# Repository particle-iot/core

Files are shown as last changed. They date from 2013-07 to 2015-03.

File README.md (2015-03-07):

The Spark Core
=====

These are the hardware design files for the Spark Core, developed by Hex Labs, Inc. dba Spark.

These files have been made available online through a [Creative Commons Attribution-ShareAlike 3.0](http://creativecommons.org/licenses/by-sa/3.0/) license.

You are welcome to distribute, remix, and use these files for commercial purposes. If you do so, please attribute the original design to Spark both on the website and on the physical packaging of the product or in the instruction manual. All derivative works must be published under the same or a similar license.

## The Story

Development of the Spark Core in its current form began in January 2013 in Shenzhen, China during Spark's participation in the HAXLR8R hardware accelerator.  Development of the Spark Cloud was started in December 2011 as software infrastructure to support the Spark Socket.  Between January and May of 2013, the Spark Core and Cloud were developed from prototypes to a functional platform for building internet-connected hardware.  On May 2, 2013, the Spark Core was launched on the crowdfunding platform Kickstarter.  On May 17, 2013, the hardware design files for the product were released here on GitHub for others to use and learn from.

## What's Included

**BOM** — Current bill of materials for the latestversion of the Spark Core.  Includes part number labels from design files, component values, quantities, and package types.

**Datasheets** — Datasheets for the various components included on the Spark Core, including the STM32F103CBT6 microcontroller and the CC3000 Wi-Fi module.

**EAGLE** — Schematic and board files for the Spark Core.  We use EAGLE, a freemium PCB design software package, for the design and development of the Spark Core.

**Gerber** — Complete set of Gerber files for the current version of the Core.  Use these files to spin up and assemble your own Cores!

**Libraries** — EAGLE libraries for the components used on the Spark Core.

**PDFs** — Includes detailed description of component placement on the Core (especially useful during assembly).  Also includes mechanical drawings and a detailed schematic of the Core for reference and debugging.

**Pin Mapping** — Detailed pin mapping of the Spark Core and STM32, providing information about which pins are mapped to which peripherals.

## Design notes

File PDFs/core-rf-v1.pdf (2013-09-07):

The pads and traces in red represent the RF net. They should be matched to 50 ohm impedance.

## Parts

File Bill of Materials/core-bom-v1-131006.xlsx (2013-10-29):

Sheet: BOM
PROJECT NAME |  | SPARK CORE
LAST UPDATED |  | 2013-10-07
COMMON PARTS
Qty | AQS P/N | Device | Minimum Specification | Component Value (if different) | Package/Case | Designator | AVL | AVL P/N | Additional Comments
1 | 303-20-301048 | Fab PCB | FR4, 1.6mm, 1OZ, Electroless Nickel Immersion Gold, White Solder Mask, Black Silkscreen
7 | 121-08-301845 | Ceramic Capacitor | 100nF, Ceramic, 10V, 10%, X5R | 25V, X7R | 0603 | C3, C6-7, C12-14, C16 | Yageo | CC0603KRX7R8BB104
2 | 121-08-301847 | Ceramic Capacitor | 10pF, Ceramic, 10V, 10%, X5R |  | 0603 | C8, C9 | RongFu | CL10C100DBANNNC
2 | 121-08-301846 | Ceramic Capacitor | 22pF, Ceramic, 10V, 10%, X5R | 50V, 5% | 0603 | C10, C11 | Yageo | CC0603JRNPO9BN220
2 | 121-08-301857 | Ceramic Capacitor | 4.7uF, Ceramic, 10V, 10%, X5R |  | 0603 | C1, C2 | Samsung Electro-Mechanics | CL10A475KP8NNNC
1 | 224-10-301005 | Chip Antenna | 2.4GHz, Ceramic |  | 8mm x 1mm | ANT1 | ACX | US PN = 2500AT44M0400E Asia PN = AT8010-E2R9HAA
1 | 150-10-301017 | Chip Resistor Array | 1K, 1/4W, 4 Resistors, 5% | 62.5mW per element | 1206 | RN1 | Panasonic Electric Components | EXB-38V102JV
1 | 211-30-301136 | Crystal | 8MHz Crystal, 18pF, SMD |  | 5032 | Y2 | Song Ji | SMD5032 4P 30M
1 | 201-55-301060 | Diode | 30V, 3A |  | DO-220AA | D1 | Vishay | SS3P3-M3/84A
1 | 221-36-301546 | Dual NPN transistor | Dual NPN, 40V |  | SOT363 | Q1 | Micro Commercial Co | MMDT3904-TP
1 | 171-10-301099 | Ferrite bead | 220Ω, 500mA |  | 0603 | L2 | Murata | BLM18AG221SN1D
2 | 515-30-301984 | Header | Single String, 0.230" Mating Length |  | 0.1", 12 pin | JP1, JP2 | Kaweei | CP25411-12G-S116-A
1 | 414-10-301282 | LED | Blue, SMD |  | 0603 | LED_USR | Wenliang | WLUB0603A-341
1 | 280-61-301021 | Microcontroller | MCU ARM 128K, 48-pin |  | LQFP48 | U2 | STMicroelectronics | STM32F103CBT6
2 | 101-15-303034 | Resistor | 10K, 1/10W, 5% |  | 0603 | R1, R8 | Vishay | CRCW060310K0JNEB
2 | 101-15-303037 | Resistor | 22Ω, 1/10W, 5% |  | 0603 | R5, R6 | Yageo | RC0603JR-0722RL
2 | 101-15-303039 | Resistor | 1K, 1/10W, 5% |  | 0603 | R4, R9 | Vishay | CRCW06031K00JNEA
1 | 101-15-303035 | Resistor | 33K, 1/10W, 5% |  | 0603 | R2 | Vishay | CRCW060333K0JNEB
1 | 101-15-303036 | Resistor | 1K5, 1/10W, 5% |  | 0603 | R3 | Vishay | CRCW06031K50JNEA
1 | 101-15-303038 | Resistor | 47K, 1/10W, 5% |  | 0603 | R7 | Vishay | CRCW060347K0JNEB
1 | 414-10-301283 | RGB LED | 3528 RGB LED |  | 3528 | LED_RGB | Wenliang | WLRGB3528C/R
1 | 211-30-301134 | RTC Crystal | 32.768KHz, 7pF RTC Crystal |  | 2-SMD | Y1 | Song Ji | SJFC1332K07P20
1 | 221-28-301637 | SPI Flash Module | 16Mbit, 75MHz |  | 8-SOIC | U3 | Microchip Technology | SST25VF016B-75-4I-S2AF-T
2 | 421-20-301035 | Tactile Switch | Button, 160gf |  | 3.6mm x 3.1mm | BTN, RESET | Haoyu | TS-1185A-C
1 | 121-12-301350 | Tantalum Capacitor | 10uF, Tantalum, 10V, 20% |  | 1206 | C15 | AVX | TAJA106M010RNJ
1 | 515-40-301729 | USB Micro B Connector | USB Micro B, SMT with TH Board Guides |  | USB-MICROB | X1 | Kaweei | CMCUSB-5BFM2G-01-D
1 | 221-36-301545 | Voltage Regulator | 3.3V, 0.5A LDO |  | SOT223 | IC1 | Microchip Technology | MCP1825S-3302E/DB
1 | 990-16-301043 | Wi-Fi Module | Wi-Fi Module |  |  | U1 | Texas Instruments | CC3000
1 | 223-40-301230 | Buffer | Non-inverting 3-state buffer |  | SOT553 | U4 | ON Semiconductor | NL17SZ125XV5T2G
UNCOMMON PARTS - CHIP(2)
Qty |  | Device | Minimum Specification | Component Value (if different) | Package/Case | Designator | AVL | AVL P/N | Additional Comments
1 | 121-08-301870 | Ceramic RF Capacitor | 0.8pF, Ceramic, 25V, ±0.25pF | 250V, ±0.1pF | 0603 | C4 | Johanson Technology Inc | 251R14S0R8BV4T | Must be RF capacitor, specified for 2.4Ghz
1 | 161-02-301079 | RF Inductor | 3.3nH, RF inductor |  | 0603 | L1 | Johanson Technology Inc | L-14C3N3SV4T | Must be RF inductor, suitable for high frequency.
UNCOMMON PARTS - UFL(1)
Qty |  | Device | Minimum Specification | Component Value (if different) | Package/Case | Designator | AVL | AVL P/N | Additional Comments
1 | 511-30-301374 | uFL Connector | IPEX-20279-001E |  | SMD | X2 | Kaweei | P1163-0140R
ACCESSORIES
Qty |  | Device | Minimum Specification | Component Value (if different) | Package/Case | Designator | AVL | AVL P/N | Additional Comments
1 | 999-20-301886 | Mini Breadboard | White, 400pt tie point |  | 3.5 x 4.5cm |  |  |  | CONSIGNED BY SPARK
1 | 433-20-301169 | USB Micro - B Cable | 0.5m, White with Cyan silkscreen |  | USB-MICROB |  |  |  | CONSIGNED BY SPARK
1 | 901-00-301344 | "STICK-VINYL-2IN" sticker | 2", Circular, PVC |  | 2" Diameter |  |  |  | CONSIGNED BY SPARK
PACKAGING
Qty |  | Device | Minimum Specification | Component Value (if different) | Package/Case | Designator | AVL | AVL P/N | Additional Comments
1 | 901-00-301345 | Cardboard Packaging | White on Kraft, Double-sided |  |  |  |  |  | CONSIGNED BY SPARK
1 | 901-00-301346 | Anti-static Foam Insert | Black, 83.5 x 63.5 x 10mm |  |  |  |  |  | CONSIGNED BY SPARK
1 | 901-00-001347 | "STICK-CORECAUPC" or "STICK-COREUFLUPC" sticker | 20 x 30mm, Cyan logo |  |  |  |  |  | CONSIGNED BY SPARK

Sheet: BOM Change History
Subject: | BOM ECO
Project Name: | Spark Core
BOM Rev.: | 130906
PCB Rev.: | v1.0
Date: | 9/6
Prepared by: | Zach
Project Name |  |  | Spark Core
Item | BOM Revision |  | Change Details | Date | Responsible
 | Old | New
1 | core-bom-v025-090213 | core-bom-v025-090413 | Updated buffer P/N from NL17SZ125 to NL17SZ125XV5T2G to specify SOT-553 package | 9/4 | Will
2 | core-bom-v025-090213 | core-bom-v025-090413 | Updated antenna designator from A1 to ANT1 | 9/4 | Will
3 | core-bom-v025-090213 | core-bom-v025-090413 | Added the MFG P/N of C8,C9 is CL10C100DBANNNC, MFG name is RongFu | 9/4 | Charlie
4 | core-bom-v025-090413 | core-bom-v1-130906 | Changed value of L1 RF inductor from 2.2nH to 3.3nH | 9/6 | Zach
5 | core-bom-v025-090413 | core-bom-v1-130906 | Changed manufacturer of RF inductor from TDK to Johanson Technology | 9/6 | Zach
6 | core-bom-v025-090413 | core-bom-v1-130906 | Changed value of C4 RF capacitor from 2.2pF to 0.8pF | 9/6 | Zach
7 | core-bom-v025-090413 | core-bom-v1-130906 | Removed C5 RF capacitor from Bill of Materials (no longer necessary) | 9/6 | Zach
8 | core-bom-v1-130906 | core-bom-v1-130924 | Updated description of breadboard, USB Cable, Vinyl sticker | 9/16 | Will
9 | core-bom-v1-130906 | core-bom-v1-130924 | Added new part: anti-static foam insert | 9/16 | Will
10 | core-bom-v1-130906 | core-bom-v1-130924 | Added new part: "coreca-upc" Sticker | 9/16 | Will
11 | core-bom-v1-130906 | core-bom-v1-130924 | Added new part: "coreufl-upc" Sticker | 9/16 | Will
12 | core-bom-v1-130906 | core-bom-v1-130924 | Added AQS part numbers to all parts where available | 9/24 | Will
13 | core-bom-v1-130906 | core-bom-v1-130924 | Added new consigned part: "Anti-static foam insert" | 9/24 | Will
14 | core-bom-v1-130924 | core-bom-v1-130926 | Added AQS part numbers to remaining components | 9/25 | Wilton
15 | core-bom-v1-130926 | core-bom-v1-131006 | Updated description of AQS part #901-00-001347 | 10/6 | Will
16 | core-bom-v1-130926 | core-bom-v1-131006 | Updated description of vinyl sticker | 10/6 | Will
17
18
19
20
21
22
23
24
25
26
27
28
29
30
31
32
33
34
35
36
37
38
39
40
41
42
43
44
45
46
47
48
49
50
.end of doc.

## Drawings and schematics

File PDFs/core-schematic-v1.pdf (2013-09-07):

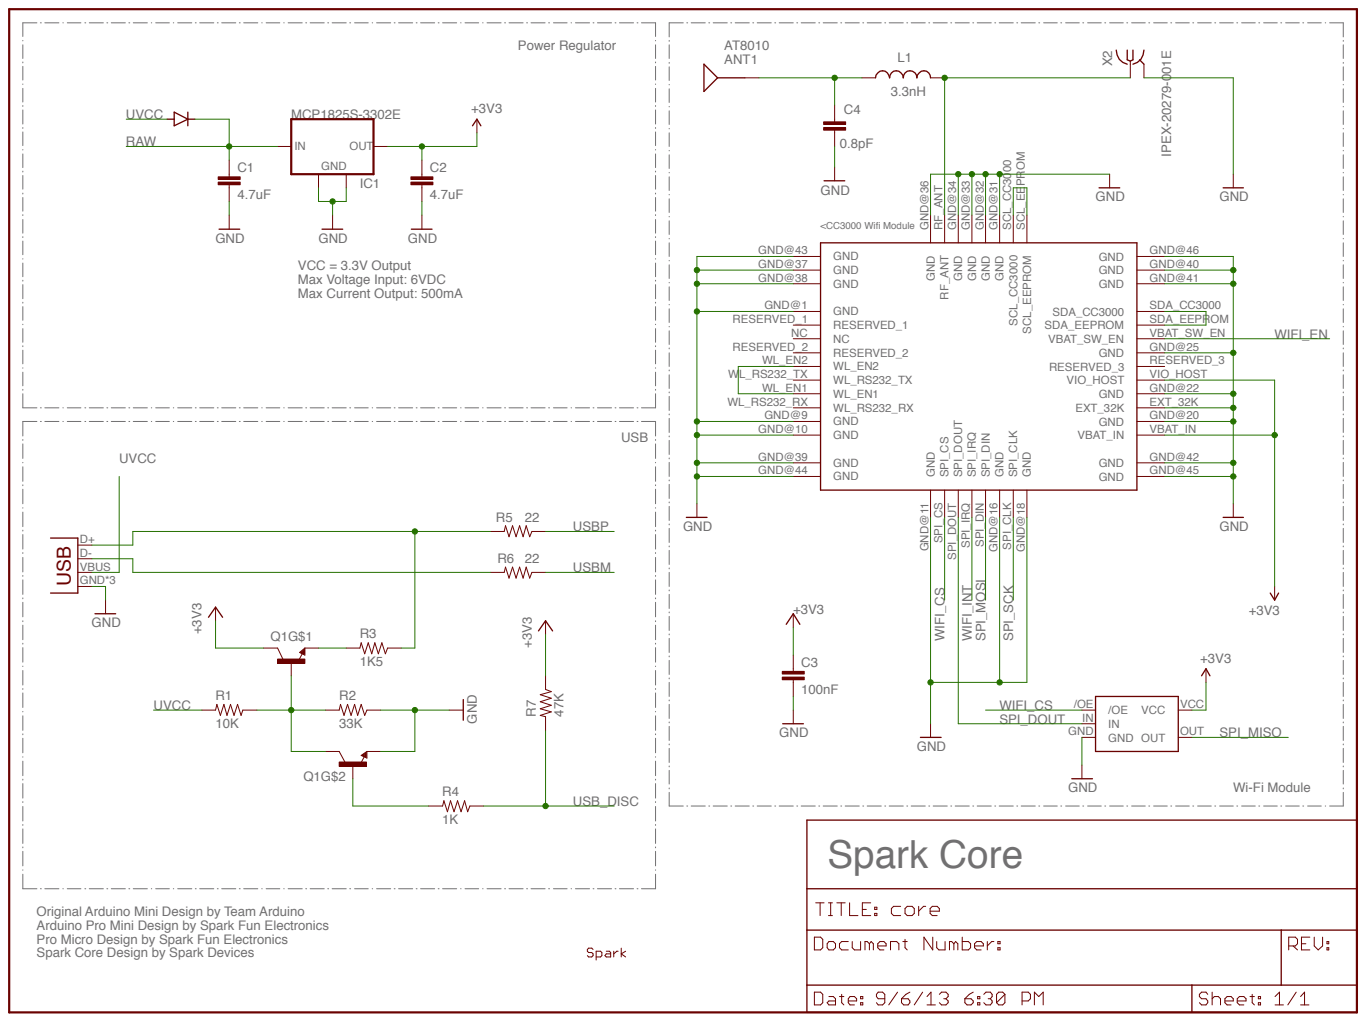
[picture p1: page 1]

SCL_EEPROM SCL_EEPROM SCL_CC3000 SCL_CC3000 GND GND@31 GND GND@32 GND GND@33 GND GND@34 RF_ANT RF_ANT GND GND@36

Original Arduino Mini Design by Team Arduino
Arduino Pro Mini Design by Spark Fun Electronics
Pro Micro Design by Spark Fun Electronics
Spark Core Design by Spark Devices

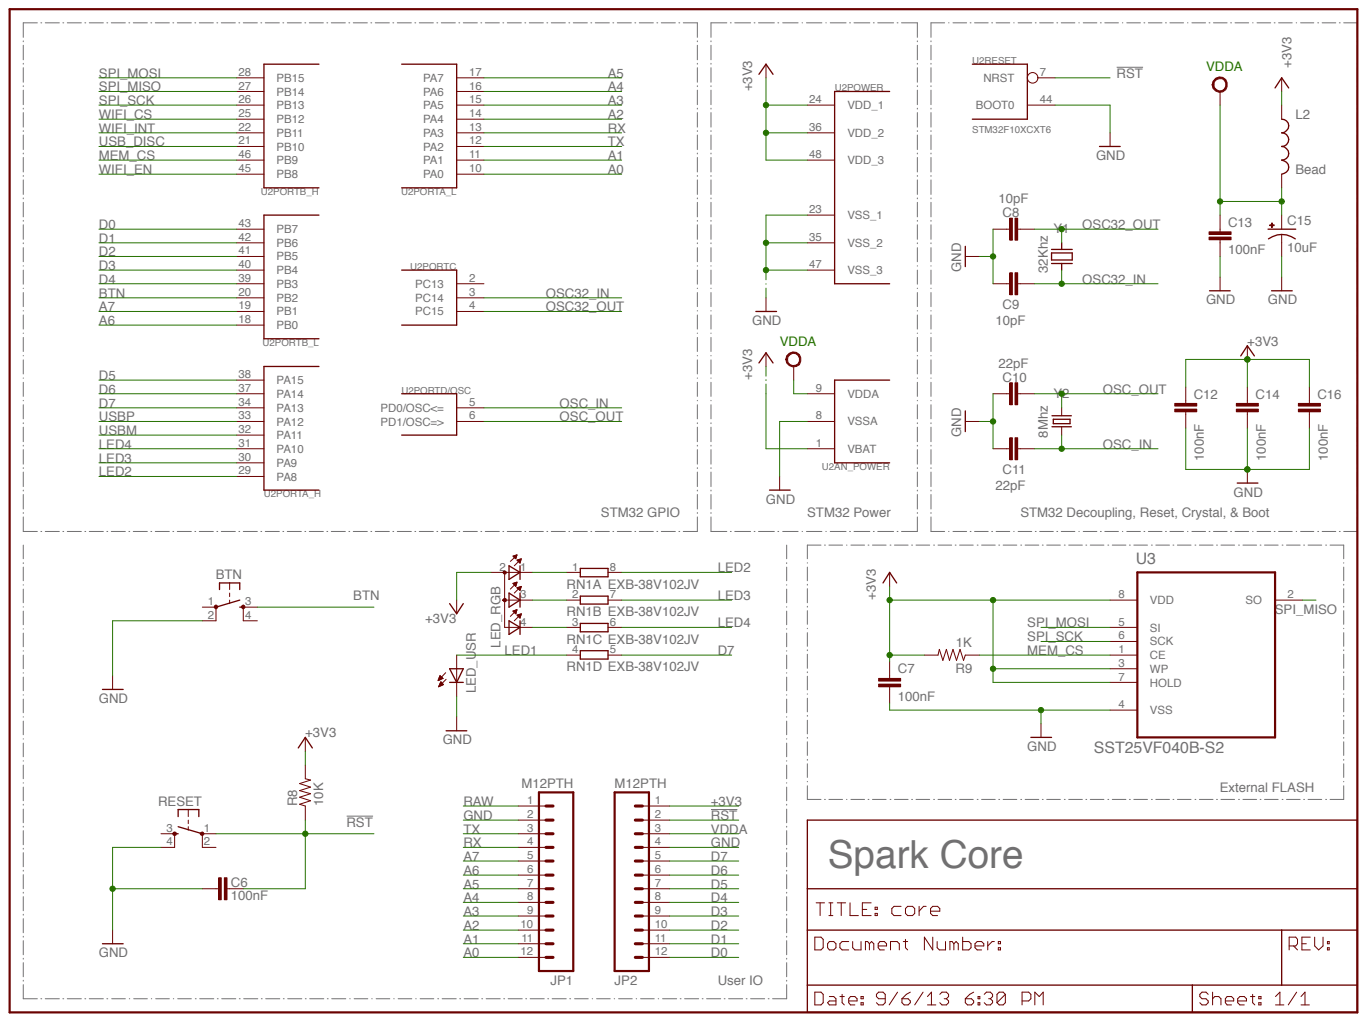
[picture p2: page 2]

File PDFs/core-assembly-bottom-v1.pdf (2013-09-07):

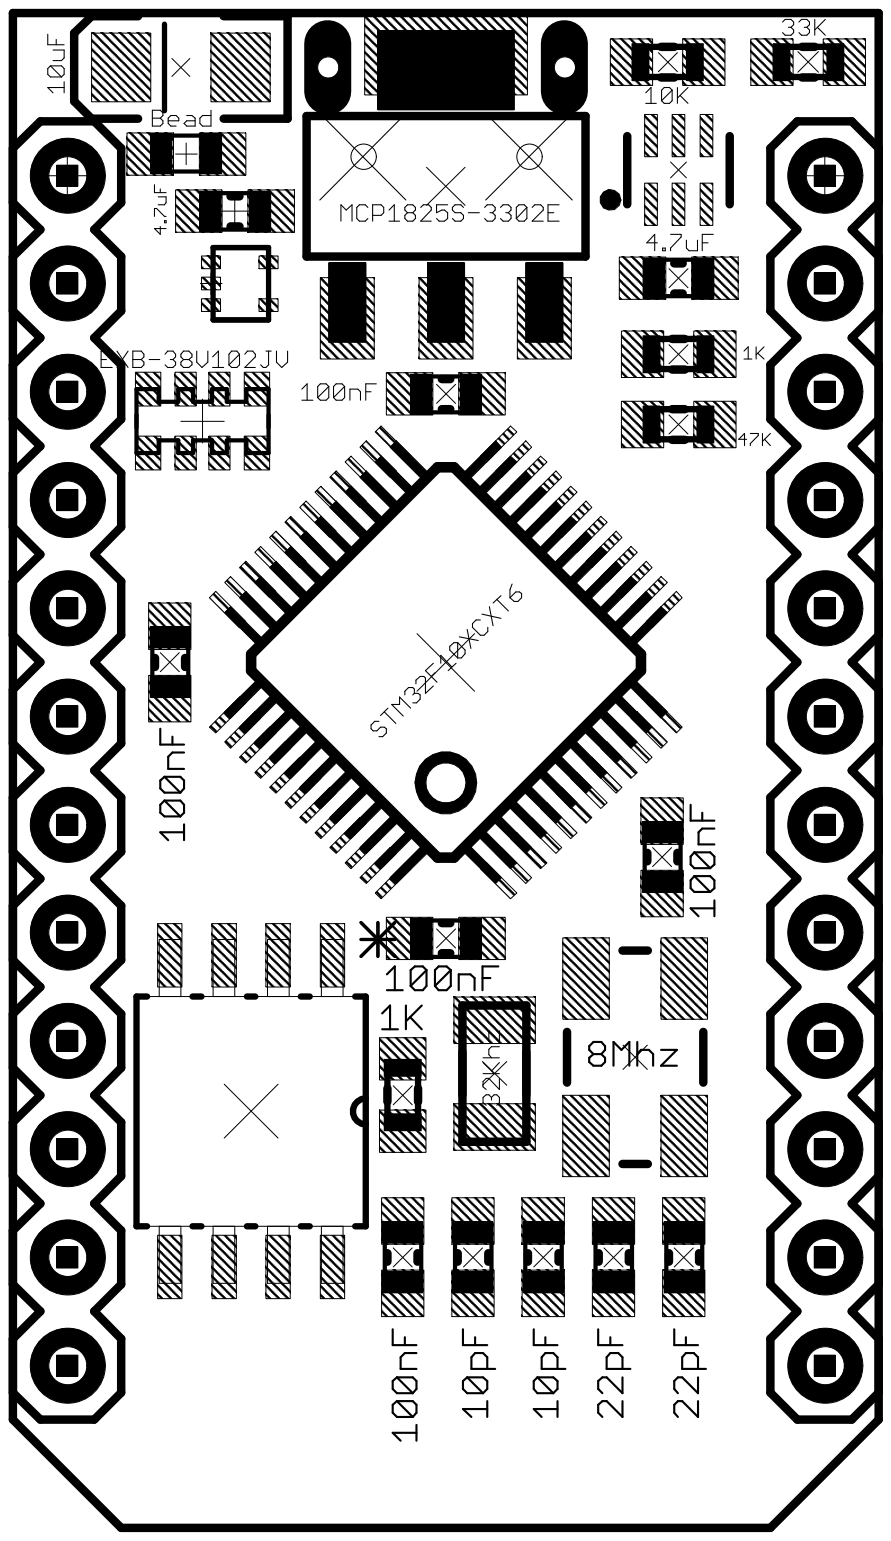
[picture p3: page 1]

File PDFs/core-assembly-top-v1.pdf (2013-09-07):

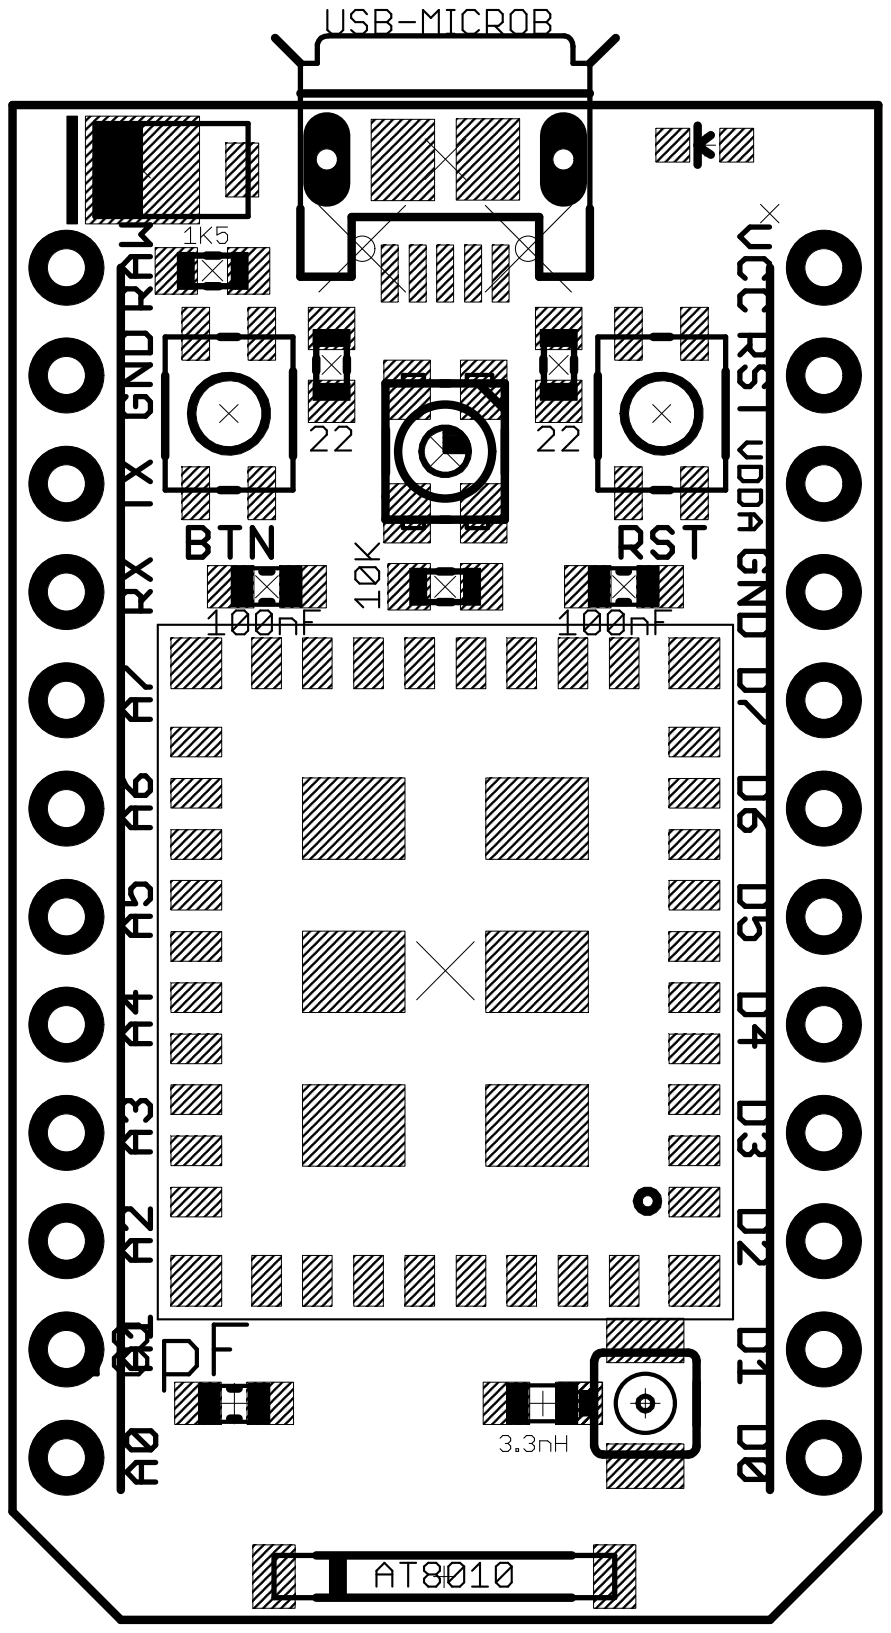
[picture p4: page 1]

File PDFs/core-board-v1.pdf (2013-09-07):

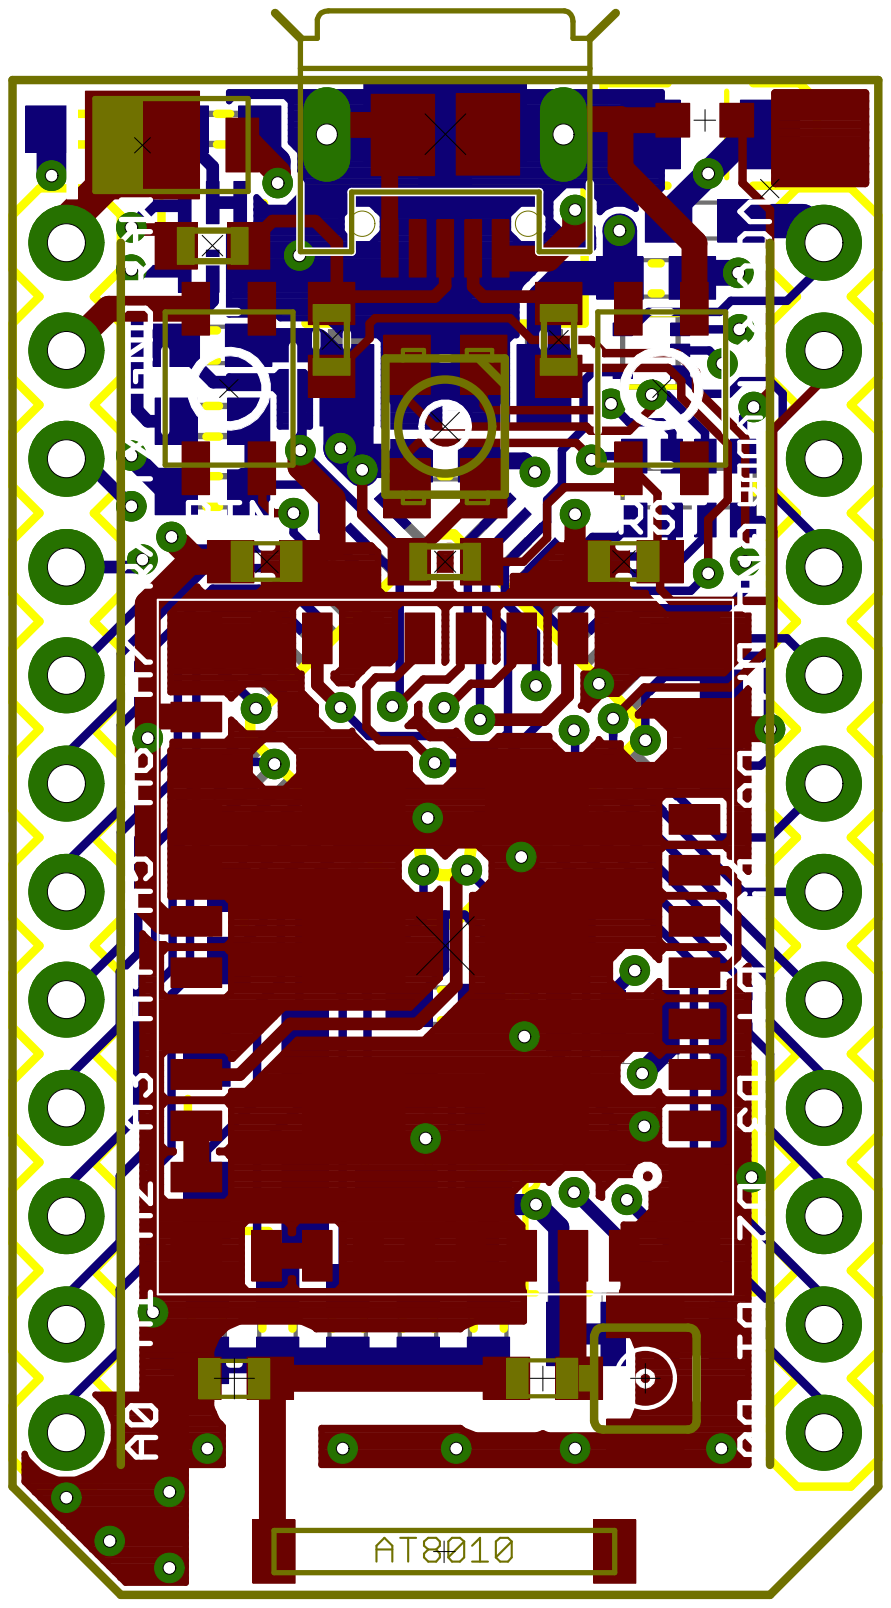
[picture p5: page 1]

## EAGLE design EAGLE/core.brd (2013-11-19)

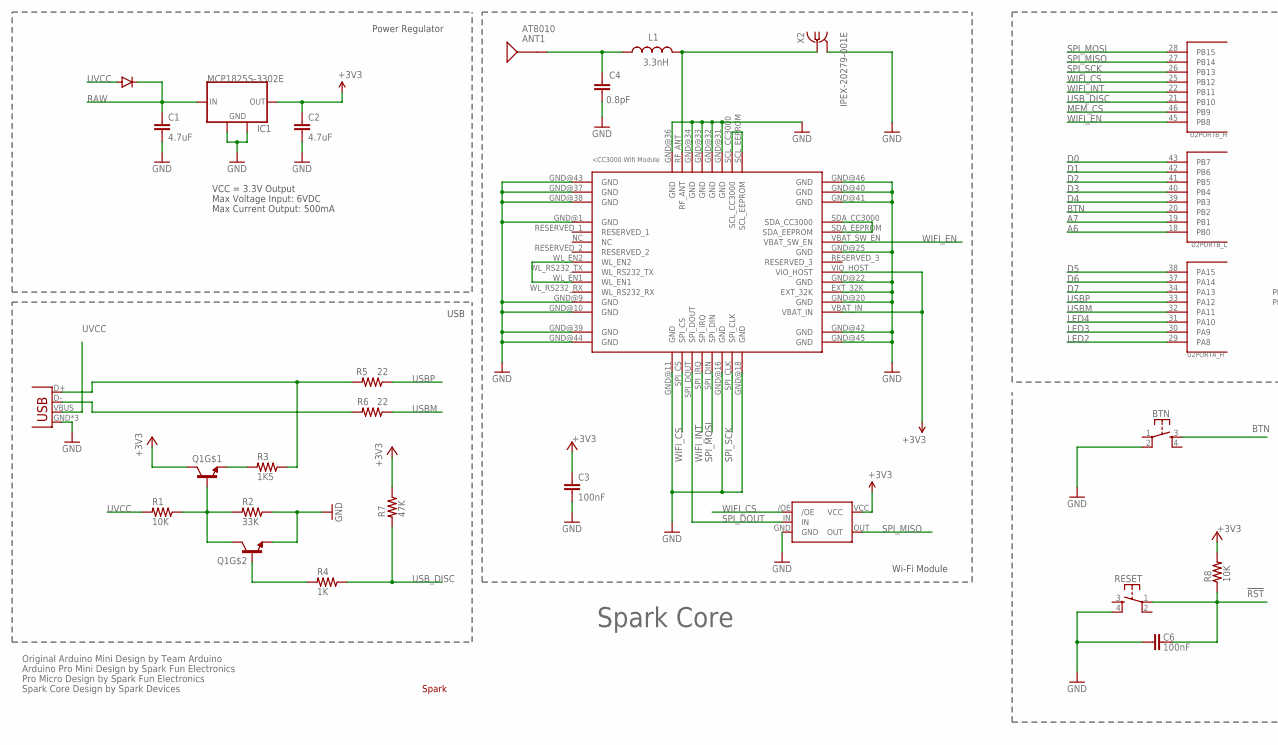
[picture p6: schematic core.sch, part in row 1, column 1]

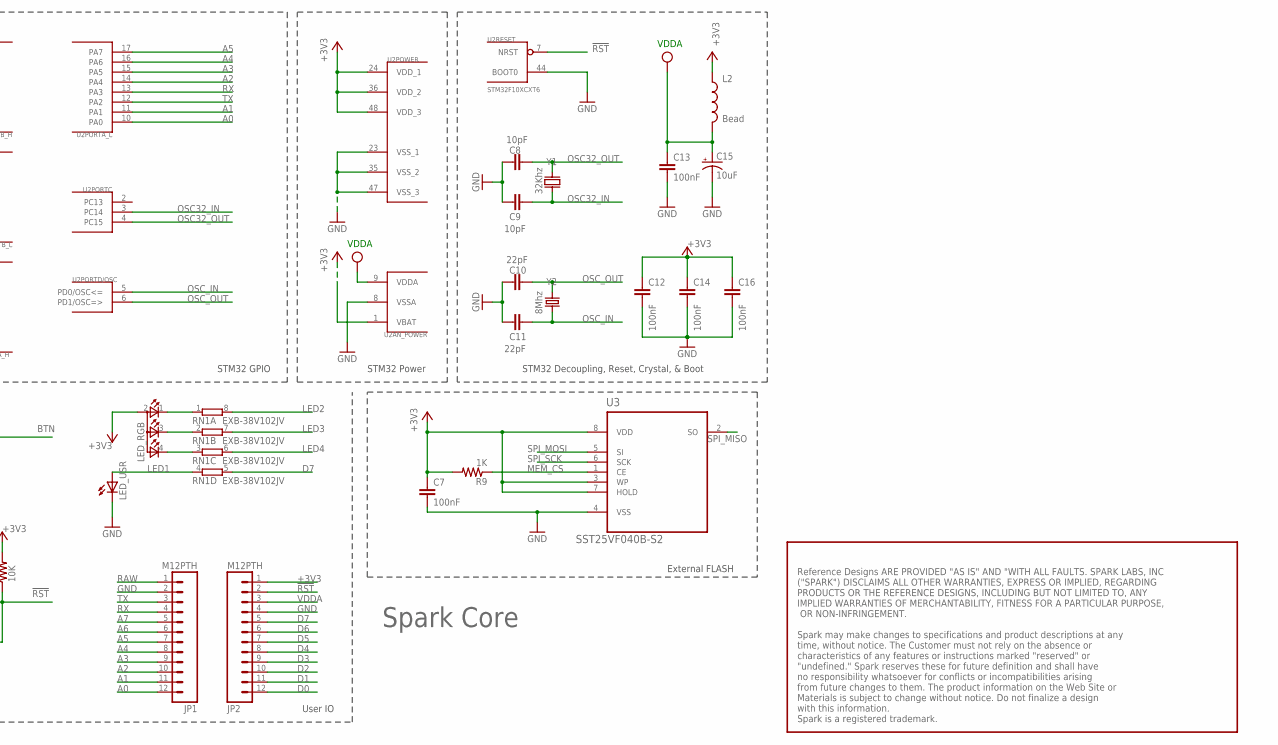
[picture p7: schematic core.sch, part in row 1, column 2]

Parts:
ANT1: AT8010
BTN: KMR211GLFS; TACTILE_SWITCH_SMD
C1, C2: 4.7uF; C0603
C3, C6, C7, C12, C13, C14, C16: 100nF; C0603
C4: 0.8pF; C0603
C8, C9: 10pF; C0603
C10, C11: 22pF; C0603
C15: 10uF; EIA3216
D1: DIODE; DIODE-DO-220AA(SMP)
IC1: MCP1825S-3302E; SOT223
JP1, JP2: M12PTH; 1X12-SMALL-PADS
L1: 3.3nH; 0603
L2: Bead; 0603
LED_RGB: TOPLED-3PLCC; P-LCC-4-3
LED_USR: LED0603; LED-0603
Q1: MMDT3904; SOT363
R1, R8: 10K; R0603
R2: 33K; R0603
R3: 1K5; R0603
R4, R9: 1K; R0603
R5, R6: 22; R0603
R7: 47K; R0603
RESET: KMR211GLFS; TACTILE_SWITCH_SMD
RN1: EXB-38V102JV; EXB38V
U1: CC3000
U2: STM32F10XCXT6; TQFP48
U3: SST25VF040B-S2; SOIC127P790X216-8N
U4: NL17SZ125SOT553; SOT-553
U$1: SPARK_LOGO2
X1: USB-MICROB; USB-MICROB-SLOT-HOLE
X2: IPEX-20279-001E
Y1: 32Khz; FC135
Y2: 8Mhz; CRYSTAL-SMD-5X3

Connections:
!RST: C6.2, JP2.2, R8.1, RESET.1, U2.7 (NRST)
+3V3: C2.1, C3.1, C7.1, C12.1, C14.1, C16.1, IC1.3 (OUT), JP2.1, L2.1, LED_RGB.2 (A2), Q1.3 (C), R7.1, R8.2, R9.2, U1.VBAT_IN, U1.VIO_HOST, U2.1 (VBAT), U2.24 (VDD_1), U2.36 (VDD_2), U2.48 (VDD_3), U3.3 (WP), U3.7 (HOLD), U3.8 (VDD), U4.VCC
A0: JP1.12, U2.10 (PA0)
A1: JP1.11, U2.11 (PA1)
A2: JP1.10, U2.14 (PA4)
A3: JP1.9, U2.15 (PA5)
A4: JP1.8, U2.16 (PA6)
A5: JP1.7, U2.17 (PA7)
A6: JP1.6, U2.18 (PB0)
A7: JP1.5, U2.19 (PB1)
BTN: BTN.3, U2.20 (PB2)
D0: JP2.12, U2.43 (PB7)
D1: JP2.11, U2.42 (PB6)
D2: JP2.10, U2.41 (PB5)
D3: JP2.9, U2.40 (PB4)
D4: JP2.8, U2.39 (PB3)
D5: JP2.7, U2.38 (PA15)
D6: JP2.6, U2.37 (PA14)
D7: JP2.5, RN1.5 (2), U2.34 (PA13)
GND: BTN.2, C1.2, C2.2, C3.2, C4.2, C6.1, C7.2, C8.2, C9.2, C10.2, C11.2, C12.2, C13.2, C14.2, C15.C (-), C16.2, IC1.2 (GND), IC1.4 (GND), JP1.2, JP2.4, LED_USR.C, Q1.1 (E), R2.1, RESET.4, U1.EXT_32K, U1.GND@1 (GND), U1.GND@9 (GND), U1.GND@10 (GND), U1.GND@11 (GND), U1.GND@16 (GND), U1.GND@18 (GND), U1.GND@20 (GND), U1.GND@22 (GND), U1.GND@25 (GND), U1.GND@31 (GND), U1.GND@32 (GND), U1.GND@33 (GND), U1.GND@34 (GND), U1.GND@36 (GND), U1.GND@37 (GND), U1.GND@38 (GND), U1.GND@39 (GND), U1.GND@40 (GND), U1.GND@41 (GND), U1.GND@42 (GND), U1.GND@43 (GND), U1.GND@44 (GND), U1.GND@45 (GND), U1.GND@46 (GND), U2.8 (VSSA), U2.23 (VSS_1), U2.35 (VSS_2), U2.44 (BOOT0), U2.47 (VSS_3), U3.4 (VSS), U4.GND, X1.GND, X1.MT1 (GND), X1.MT2 (GND), X2.2@1 (GND), X2.2@2 (GND)
LED1: LED_USR.A, RN1.4 (1)
LED2: RN1.8 (2), U2.29 (PA8)
LED3: RN1.7 (2), U2.30 (PA9)
LED4: RN1.6 (2), U2.31 (PA10)
MEM_CS: R9.1, U2.46 (PB9), U3.1 (CE)
unnamed: R3.1, R5.2, X1.D+
unnamed: L1.2, U1.RF_ANT, X2.1
unnamed: ANT1.SIG, C4.1, L1.1
unnamed: R6.2, X1.D-
unnamed: U1.SCL_CC3000, U1.SCL_EEPROM
unnamed: Q1.2 (B), R4.2
unnamed: U1.WL_EN1, U1.WL_EN2
unnamed: LED_RGB.1 (CRED), RN1.1
unnamed: LED_RGB.3 (CBLUE), RN1.2 (1)
unnamed: Q1.5 (B), Q1.6 (C), R1.1, R2.2
unnamed: LED_RGB.4 (CGREEN), RN1.3 (1)
unnamed: U1.SDA_CC3000, U1.SDA_EEPROM
unnamed: Q1.4 (E), R3.2
OSC32_IN: C9.1, U2.3 (PC14), Y1.X1 (1)
OSC32_OUT: C8.1, U2.4 (PC15), Y1.X2 (2)
OSC_IN: C11.1, U2.5 (PD0/OSC<=), Y2.1
OSC_OUT: C10.1, U2.6 (PD1/OSC=>), Y2.3 (2)
RAW: C1.1, D1.CATHODE, IC1.1 (IN), JP1.1
RX: JP1.4, U2.13 (PA3)
SPI_DOUT: U1.SPI_DOUT, U4.IN
SPI_MISO: U2.27 (PB14), U3.2 (SO), U4.OUT
SPI_MOSI: U1.SPI_DIN, U2.28 (PB15), U3.5 (SI)
SPI_SCK: U1.SPI_CLK, U2.26 (PB13), U3.6 (SCK)
TX: JP1.3, U2.12 (PA2)
USBM: R6.1, U2.32 (PA11)
USBP: R5.1, U2.33 (PA12)
USB_DISC: R4.1, R7.2, U2.21 (PB10)
UVCC: D1.ANODE, R1.2, X1.VBUS
VDDA: C13.1, C15.A (+), JP2.3, L2.2, U2.9 (VDDA)
WIFI_CS: U1.SPI_CS, U2.25 (PB12), U4./OE
WIFI_EN: U1.VBAT_SW_EN, U2.45 (PB8)
WIFI_INT: U1.SPI_IRQ, U2.22 (PB11)

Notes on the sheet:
Original Arduino Mini Design by Team Arduino
Arduino Pro Mini Design by Spark Fun Electronics
Max Voltage Input: 6VDC
Max Current Output: 500mA
Power Regulator
VCC = 3.3V Output
Pro Micro Design by Spark Fun Electronics
Spark Core Design by Spark Devices
STM32 Decoupling, Reset, Crystal, & Boot
STM32 GPIO
STM32 Power
External FLASH
User IO
USB
Spark Core
Wi-Fi Module
VDDA
Reference Designs ARE PROVIDED "AS IS" AND "WITH ALL FAULTS. SPARK LABS, INC ("SPARK") DISCLAIMS ALL OTHER WARRANTIES, EXPRESS OR IMPLIED, REGARDING PRODUCTS OR THE REFERENCE DESIGNS, INCLUDING BUT NOT LIMITED TO, ANY IMPLIED WARRANTIES OF MERCHANTABILITY, FITNESS FOR A PARTICULAR PURPOSE, OR NON-I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

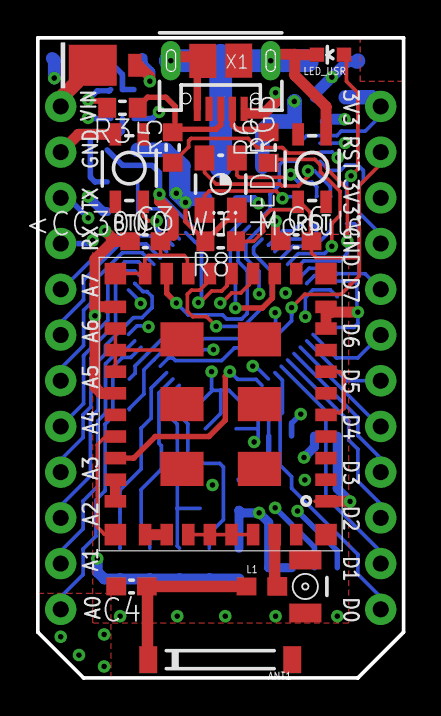
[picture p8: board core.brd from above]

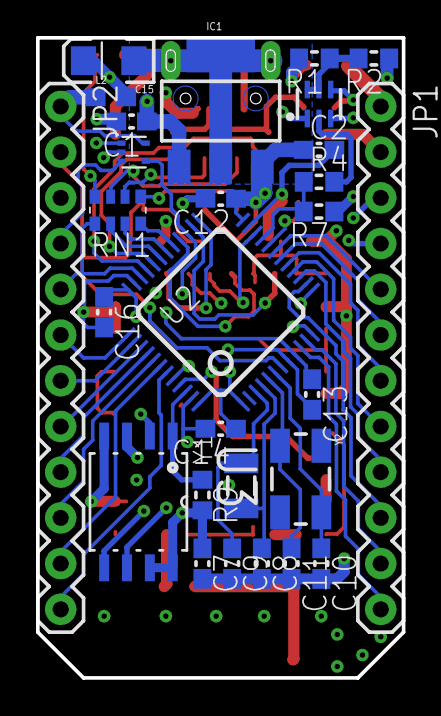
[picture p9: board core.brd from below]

Board: 4 copper layers, 20.3 x 35.6 mm, 46 parts (28 on the bottom side), 57 nets.

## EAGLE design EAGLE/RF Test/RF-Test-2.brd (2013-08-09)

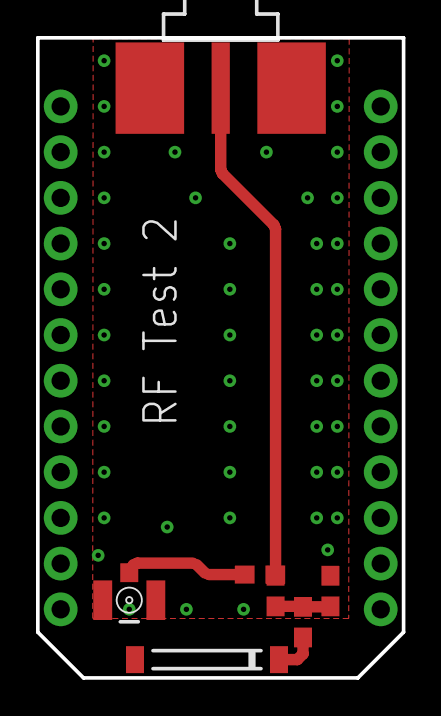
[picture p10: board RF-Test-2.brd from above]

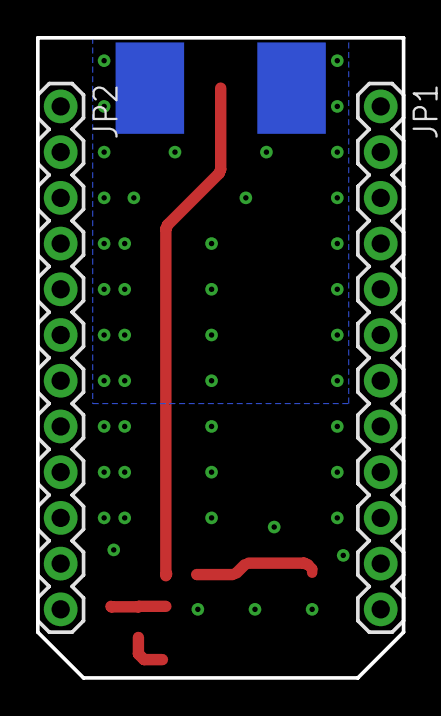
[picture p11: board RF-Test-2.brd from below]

Board: 4 copper layers, 20.3 x 35.6 mm, 9 parts (2 on the bottom side), 5 nets.

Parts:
ANT1: AT8010
C4: 2.2pF; C0603
C12, C16: 10pF; C0603
JP1, JP2: 1X12
L1: 2.2nH; 0603
X1: SMA-142-0701-881/886; ANDYW-GENERIC-END-LAUNCH
X2: IPEX-20279-001E

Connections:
GND: JP1.2, JP2.4, L1.2, X1.G@1, X1.G@2, X1.G@3, X1.G@4, X2.2@1, X2.2@2
unnamed: C16.2, X2.1
unnamed: ANT1.SIG, C4.1
unnamed: C12.2, C16.1, X1.1
unnamed: C4.2, C12.1, L1.1

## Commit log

2013-03-24 First commit; complete board and schematic, untested
    [core-pin-mapping.xlsx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]
2013-03-25 Cleaned up fie structure
    [core-pin-mapping.xlsx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]
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2013-03-25 Updated with Andy's feedback
    [core-pin-mapping.xlsx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]
2013-03-26 Tweaked board to remove 90 degree angles
    [core.brd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]
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2013-03-28 Added Bill of Materials
    [core-bom.xlsx, core.sch, programmer-shield-cnc.brd]
2013-03-28 Added part numbers for all parts
    [core-bom.xlsx]
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2013-03-31 Fixed re-numbering error by pulling in old board/schematic from 131d9d4
    [core.brd, core.sch]
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2013-04-02 Created gerber files for Core v0.0.6 and re-designed programmer shield
    [core.GBL, core.GBO, core.GBP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]
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2013-04-05 Updated EAGLE files with new WIFI_EN and WIFI_INT pins and better grounding
    [core.brd, core.sch]
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2013-04-08 Fixed MOSI/MISO error in Core
    [core.brd, core.sch]
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2013-04-10 Updated BOM and Debug board to prep for assembly
    [core-bom-v006.xlsx, core-bom-v008.xlsx, core-debug.brd]
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2013-05-02 Better USB, improved power layout, got rid of resistor near antenna
    [core.brd, core.sch]
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2013-06-27 WIP for Issue #5, #7, #8, #9
    [core.brd, core.sch]
2013-06-27 Moved crystals and capacitors away from RF area
    [core.brd, core.sch]
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2013-06-28 Schematic completed as per latest issues list (Ready for review)
    [core.brd, core.sch]
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2013-06-28 Laid out RF area, tweaked SPI flash area, placed buttons and LED
    [core.brd]
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2013-06-30 Proposed RF layout.
    Added C12 and overlay common pad with C16.
    Added top ground plane - extended back under CC3000
    Moved Antenna closer to centre line of module.
    [core.brd, core.sch]
2013-07-01 First pass at RF test board to evaluate quality and performance of RF component placement.
    To be connected directly to VNA for S11 (and S12 in the case of u.FL connector.)
    Can also be used with signnal generator to estimate antenna radiation pattern.
    [RF-Test-1.brd, RF-Test-1.sch]
2013-07-01 Minor twak of SMA position. Remove thermals on bottom layer.
    [RF-Test-1.brd]
2013-07-01 Updated Schematic - Added Tantalum Cap for VDDA and Rearranged RGB Wiring
    [core.sch]
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2013-07-01 Partial completed routing for end of the day
    [core.brd]
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2013-07-02 Tactile switch replaced in Schematic and Layout
    [core.brd, core.sch]
2013-07-02 Components Locked and PCB Manual Routing 90% completed
    [core.brd]
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2013-07-03 Replaced C16 - Tantalum 0603 with Tantalum 1206
    [core.brd, core.sch]
2013-07-03 Rearranged placement and routing of Crystal and SPI Flash area
    [core.brd]
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2013-07-12 Added fab note to BoM file; added DFM report
    [DFM report-bunnie_Peter comment.xls, core-bom-v021.xlsx]
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2013-07-12 Added fab note and data sheets for antenna and USB connector
    [core-bom-v021.xlsx]
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2013-07-17 Issue#22 modified and added the 1x12 pin header with smaller pads and holes to the spark library. Also modified the Core PCB with the updated header file issue#22 closed
    [core.brd, core.sch]
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2013-07-18 Updated the PCB Layout with the new slotted hole USB connector
    [core.brd, core.sch]
2013-07-18 Removed 2/5 vias from REG pad and shifted the GND via away from CC3000 pad
    [core.brd]
2013-07-18 Added a GND copper pour on the bottom layer around the Regulator pad
    [core.brd]
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2013-07-18 Added CC3000 Pin 1 mark on PCB top silkscreen layer
    [core.brd]
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2013-07-18 Updated BOM and Datasheets
    Updated the core-bom-v021 based on actual parts ordered for production.
    Uploaded named PDF datasheets for every component with exception given
    to the RF capacitors that are still out for quotation and ordering.
    [core-bom-v021.xlsx]
2013-07-18 DRC Error checked, fault fixed and approved
    [core.brd, core.sch]
2013-07-18 Shifted decoupling caps a bit away from the STM32
    [core.brd]
2013-07-18 Moved vias away from GND pads just a tad
    [core.brd]
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2013-07-21 Second revision of the RF Test board.
    Changes:
    1. 50Ohm trace width tweaked to 23mil (not so important since we will specify controlled impedance.)
    2. SMA footprint changed to accomodate 0.25" SMA connectors and present less of an impedance bump
    3. vias moved out of u.FL pads
    4. L1 silkscreen removed
    [RF-Test-2.brd, RF-Test-2.sch]
2013-07-23 Updated BoM
    Updated the BOM to include Johanson RF passives.
    [core-bom-v021.xlsx]
2013-07-23 RF-Test-2 Gerbers
    Changed traces to 25mil, generated RF-Test-2 gerbers.
    [RF-Test-1.GBL, RF-Test-1.GBO, RF-Test-1.GBP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]
2013-07-24 Updated BOM
    Reverted back to 1/10W resistors, updated 3 ceramic capacitors with
    approved substitutes based on lead time and availability.
    [core-bom-v021.xlsx]
2013-07-24 Further BoM Corrections
    Updated 22Ohm P/N and last edited date
    [core-bom-v021.xlsx]
2013-07-30 Removed vias in voltage regulator pad, resolved Issue #34
    [core.brd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]
2013-07-30 Moved vias out from under the u.FL connector
    [core.brd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]
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2013-08-01 Fixed power plane
    [core.brd]
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2013-08-03 Updated BOM
    Updated all capacitors and resistors to reflect components purchase.
    [core-bom-v021.xlsx]
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2013-08-08 added diode, maintained changed RGB LED footprint, moved the PCB
    [core.brd, core.sch]
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2013-08-09 Fixed up BoM
    [core-bom-v021.xlsx, core-bom-v023.xlsx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]
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2013-08-13 added the buffer on the MISO line of the CC3000
    [core.brd, core.sch]
2013-08-13 Fixed DRC errors and Updated PCB routing and Power plane polygons
    [core.brd, core.sch]
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2013-08-14 Fixed assembly sheet
    [core.brd]
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2013-08-14 Tweaked schematic and board layout for alternate matching components (parallel then series)
    [core.brd, core.sch]
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2013-08-15 changed the net from WIFI_EN to WIFI_CS on the buffer chip
    [core.brd, core.sch]
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2013-09-04 Fixed library part for RF capacitor
    [core.brd, core.sch]
2013-09-06 updated the ufl footprint and changed the net from wifi_en to wifi_cs
    [core.brd, core.sch]
2013-09-06 Cleaned up board and approved erc/drc errors
    [core.brd, core.sch]
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2013-09-07 Added old ECO Changes
    Inserted old ECO changes from previous BOMs
    [core-bom-v1-130906.xlsx]
2013-09-13 increased the copper clearance around the two mounting holes on the USB connector
    [core.brd, core.sch]
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2013-09-19 added keepout on gnd layer around the oval pads of the USB connector
    [core.brd]
2013-09-24 added anular rings aroung the USB oval pads on 3V3 and GND layers
    [core.GBL, core.GBO, core.GBP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]
2013-10-05 Updated BOMs
    Updated BOMs with AQS part numbers recent as of 130926
    [core-bom-v1-130924.xlsx, core-bom-v1-130926.xlsx]
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2013-10-29 Minor BOM tweaks
    Minor BOM tweaks updated current as of 10/6
    [core-bom-v1-130926.xlsx, core-bom-v1-131006.xlsx]
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

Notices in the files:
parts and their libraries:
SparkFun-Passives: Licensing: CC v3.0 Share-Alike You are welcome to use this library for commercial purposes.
